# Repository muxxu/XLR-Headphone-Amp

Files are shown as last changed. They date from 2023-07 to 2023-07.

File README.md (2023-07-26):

## Symmetric XLR Headphone Amplifier

In this repo you will find a headphone amplifier mainly developed for in-ear monitoring.

The amplifier is designed to be driven with symmetrical audio signals connected via XLR. It converts the symmetrical signals (Left and Right for stereo or only Right for mono, switchable) to an unsymmetrical signal. This signal is further amplified to drive headphones or in-ears. Beside the complete eagle schematics and board files, the repo contains a 3D printable casing. It is designed so that it can be attached to your belt. The amplifier is powered by 2-AA battery cells. These should last easily 50 hours, so enough time for some band sessions or concerts.

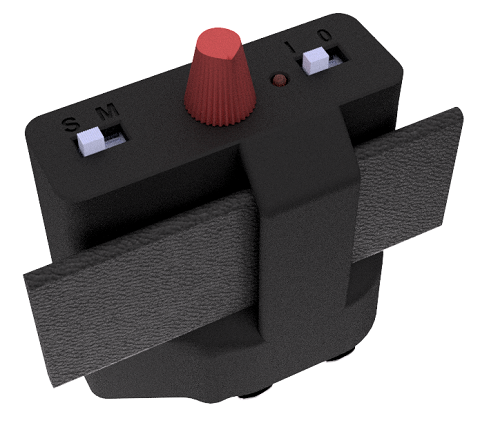
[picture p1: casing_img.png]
Image of Casing

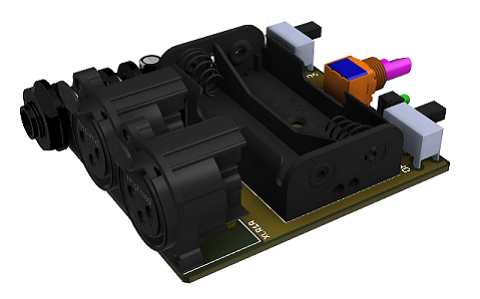
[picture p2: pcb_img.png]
Image of PCB


If you are interested in building one or have any questions feel free to contact me.

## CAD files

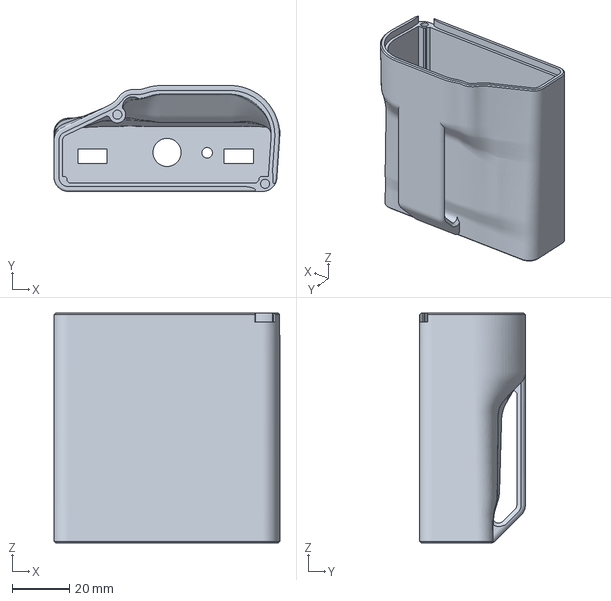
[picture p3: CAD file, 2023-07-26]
casing/mainbody.3mf
78.8 x 36.9 x 80.1 mm

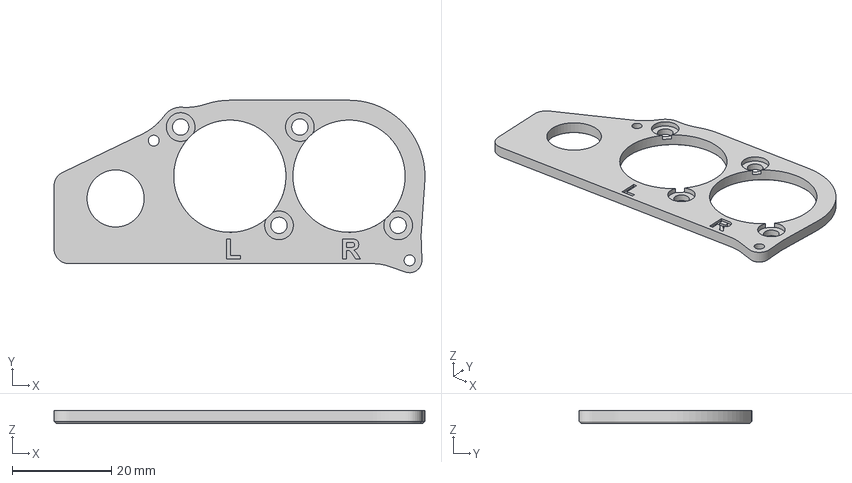
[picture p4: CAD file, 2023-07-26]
casing/cover.3mf
74.7 x 34.8 x 2.60 mm

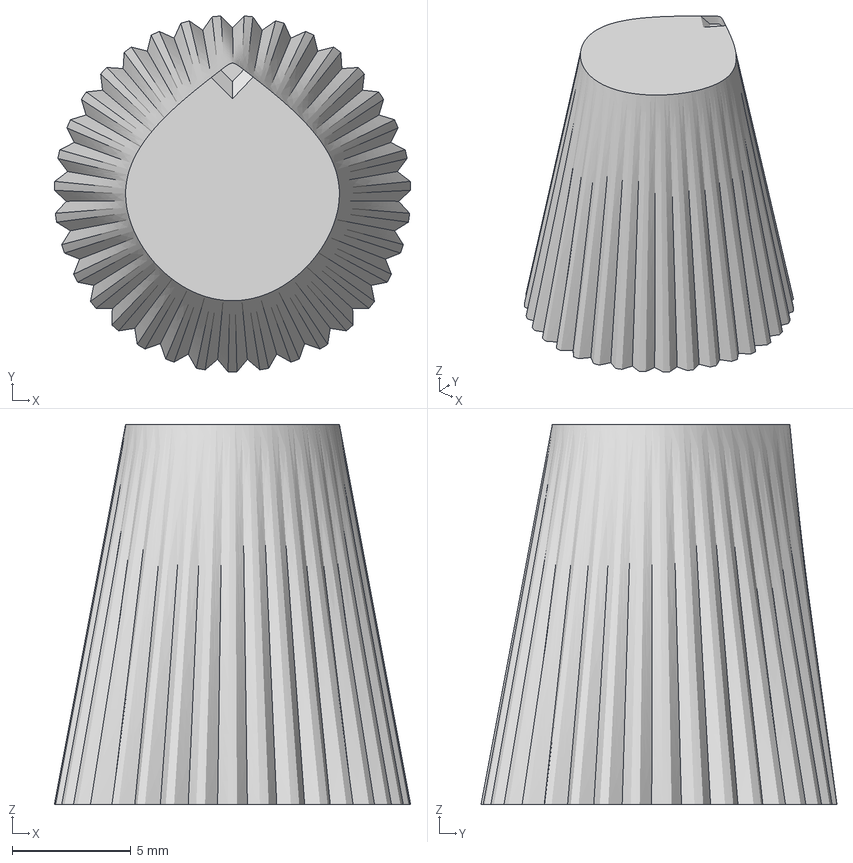
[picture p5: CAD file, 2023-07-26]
casing/knob.3mf
15.0 x 15.0 x 16.0 mm

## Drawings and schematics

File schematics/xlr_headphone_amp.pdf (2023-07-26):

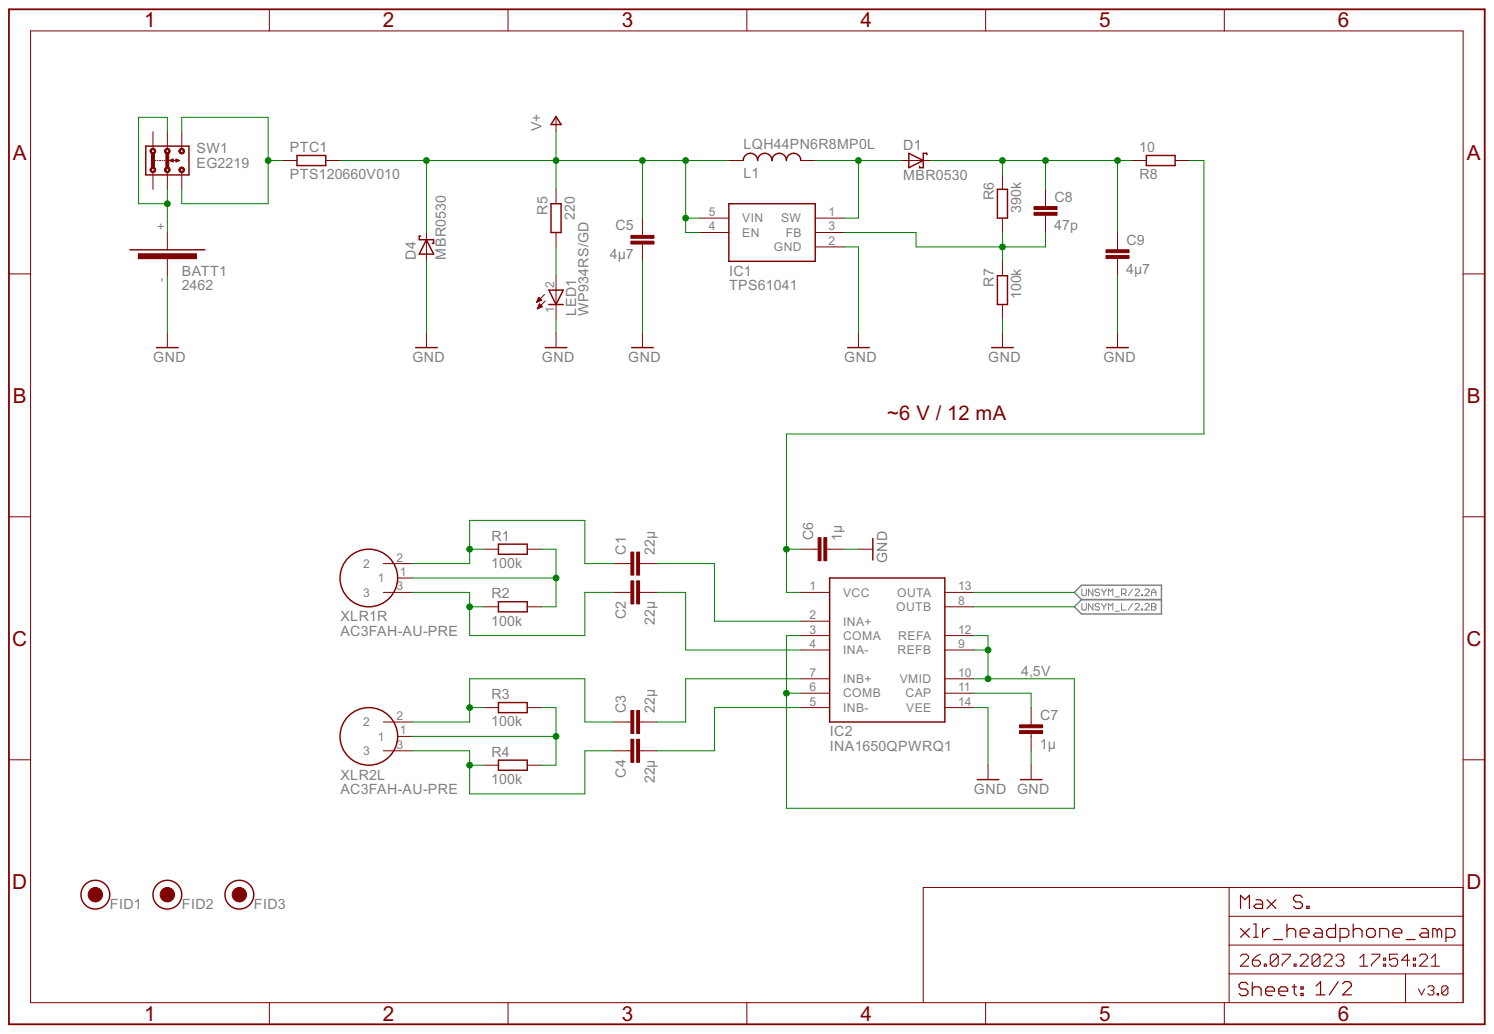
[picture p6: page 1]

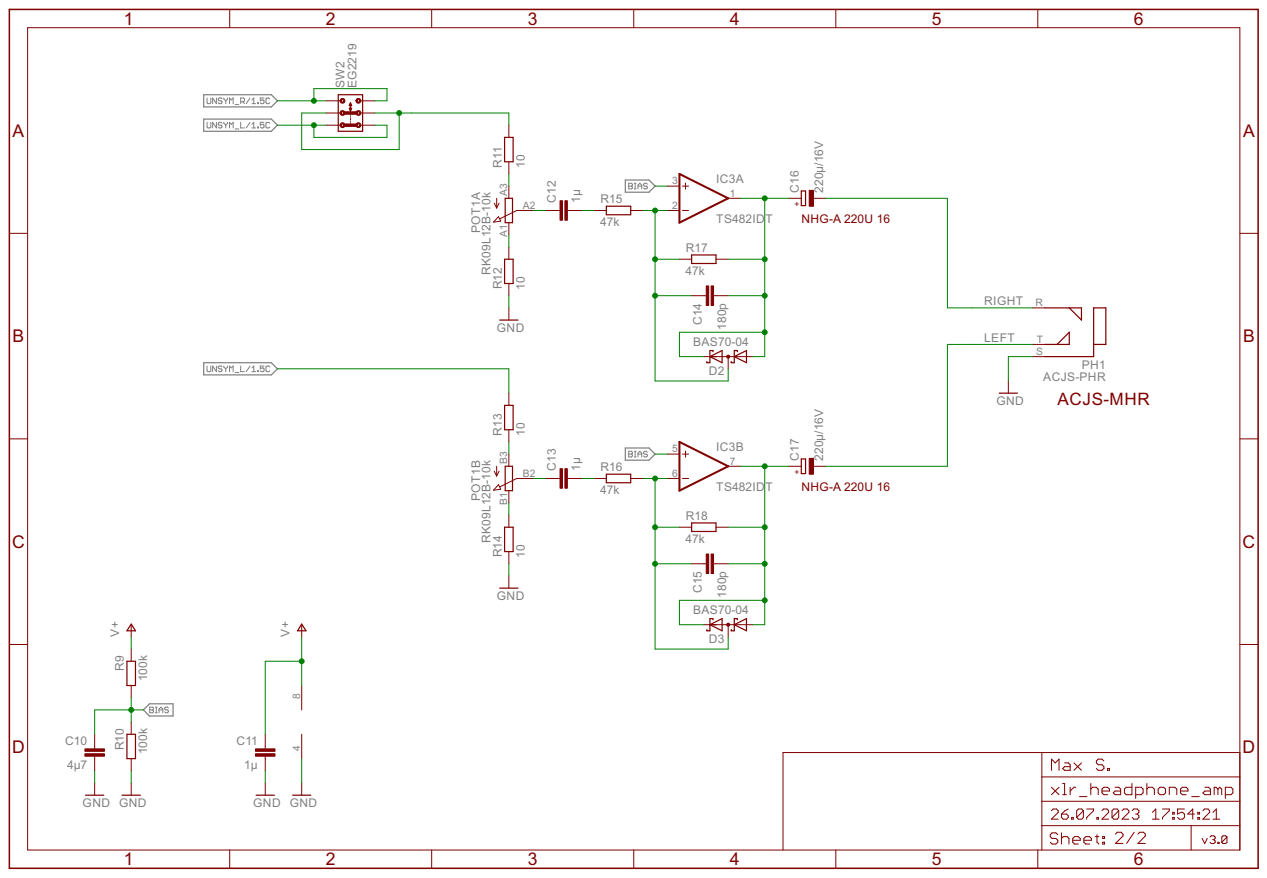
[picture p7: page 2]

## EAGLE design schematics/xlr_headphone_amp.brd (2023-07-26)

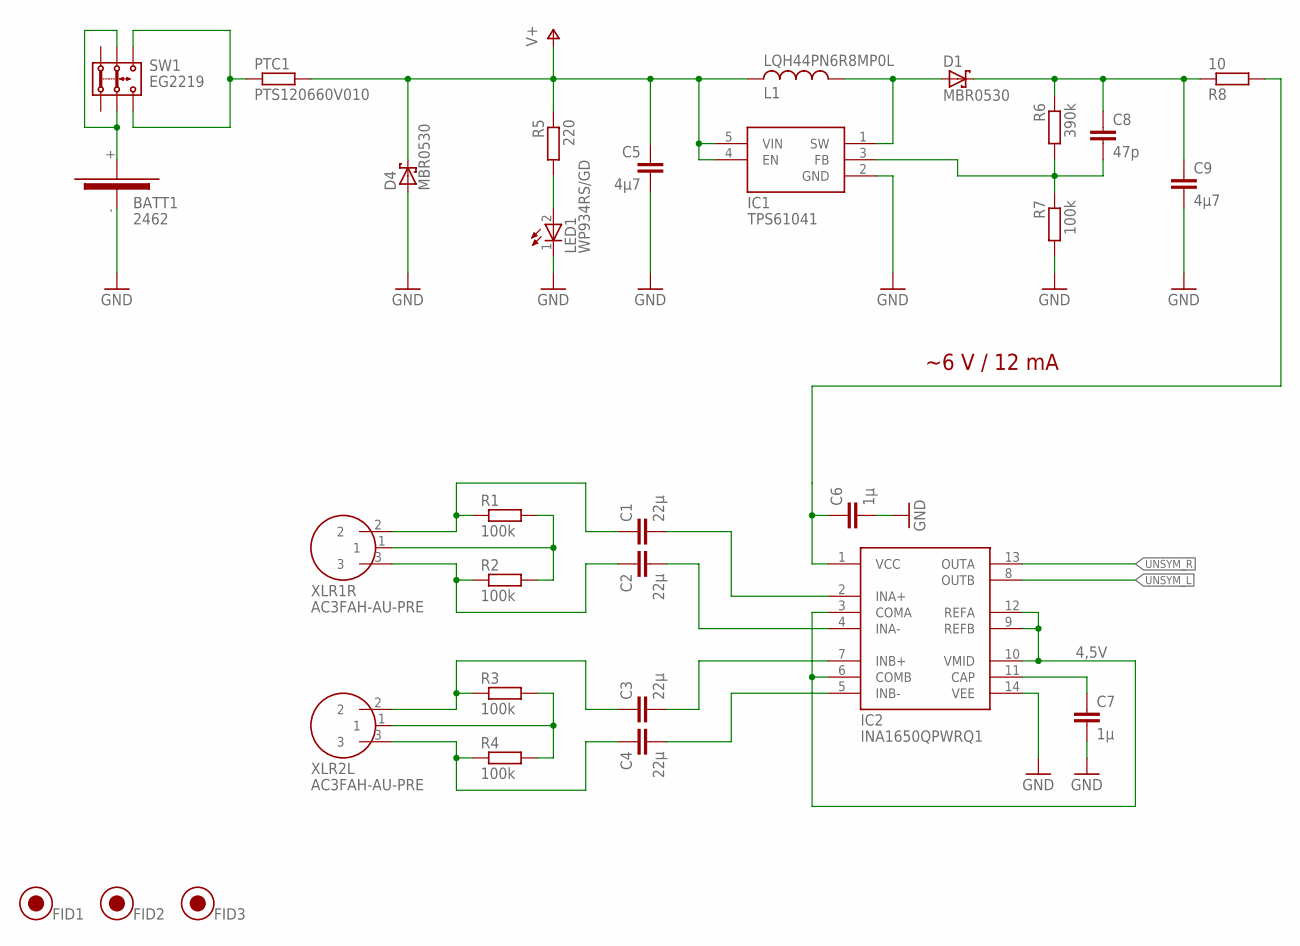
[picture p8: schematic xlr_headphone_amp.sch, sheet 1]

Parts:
BATT1: 2462
C1, C2, C3, C4: 22µ; C1206
C5, C9: 4µ7; C1206
C6, C7: 1µ; C1206
C8: 47p; C1206
D1, D4: MBR0530; SOD123
FID1, FID2, FID3: FIDICUAL
IC1: TPS61041; SOT23-5
IC2: INA1650QPWRQ1; R-PDSO-G14
L1: LQH44PN6R8MP0L; L1515(4040)
LED1: WP934RS/GD; WP934
PTC1: PTS120660V010; R1206
R1, R2, R3, R4, R7: 100k; R1206
R5: 220; R1206
R6: 390k; R1206
R8: 10; R1206
SW1: EG2219
XLR1R, XLR2L: AC3FAH-AU-PRE; AC3FAH

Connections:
4,5V: IC2.3 (COMA), IC2.6 (COMB), IC2.9 (REFB), IC2.10 (VMID), IC2.12 (REFA)
GND: BATT1.- (NEG), C5.2, C6.2, C7.2, C9.2, D4.A, IC1.2 (GND), IC2.14 (VEE), LED1.1 (C), R7.2; also elsewhere on the board
unnamed: R1.2, R2.2, XLR1R.1
unnamed: C1.1, R1.1, XLR1R.2
unnamed: C2.1, R2.1, XLR1R.3
unnamed: C1.2, IC2.2 (INA+)
unnamed: C2.2, IC2.4 (INA-)
unnamed: R3.2, R4.2, XLR2L.1
unnamed: C3.1, R3.1, XLR2L.2
unnamed: C4.1, R4.1, XLR2L.3
unnamed: C3.2, IC2.7 (INB+)
unnamed: C4.2, IC2.5 (INB-)
unnamed: C7.1, IC2.11 (CAP)
unnamed: LED1.2 (A), R5.2
unnamed: D1.A, IC1.1 (SW), L1.1
unnamed: C8.2, IC1.3 (FB), R6.2, R7.1
unnamed: C8.1, C9.1, D1.C, R6.1, R8.1
unnamed: BATT1.+ (POS), SW1.B1, SW1.B2
unnamed: PTC1.1, SW1.C1, SW1.C2
unnamed: C6.1, IC2.1 (VCC), R8.2
UNSYM_L: IC2.8 (OUTB); also elsewhere on the board
UNSYM_R: IC2.13 (OUTA); also elsewhere on the board
V+: C5.1, D4.C, IC1.4 (EN), IC1.5 (VIN), L1.2, PTC1.2, R5.1; also elsewhere on the board

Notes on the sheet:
~6 V / 12 mA

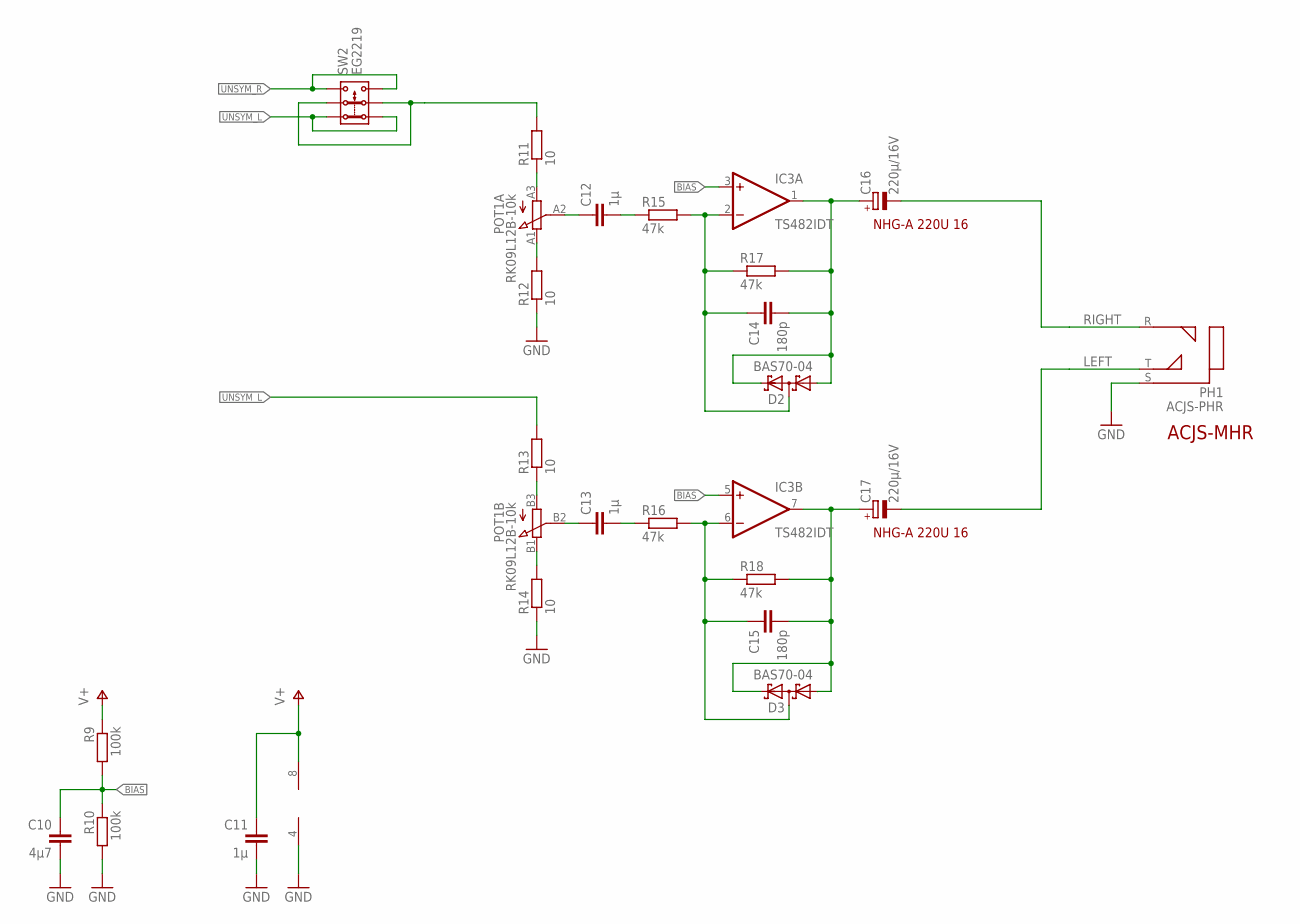
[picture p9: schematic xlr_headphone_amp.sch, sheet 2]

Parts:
C10: 4µ7; C1206
C11, C12, C13: 1µ; C1206
C14, C15: 180p; C1206
C16, C17: 220µ/16V; E2,5-6
D2, D3: BAS70-04; SOT23
IC3: TS482IDT; SO08
PH1: ACJS-PHR; ACJS
POT1: RK09L12B-10k; RK09L12
R9, R10: 100k; R1206
R11, R12, R13, R14: 10; R1206
R15, R16, R17, R18: 47k; R1206
SW2: EG2219

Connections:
BIAS: C10.1, IC3.3 (+IN), IC3.5 (+IN), R9.2, R10.1
GND: C10.2, C11.2, IC3.4 (V-), PH1.S, R10.2, R12.1, R14.1; also elsewhere on the board
LEFT: C17.-, PH1.T
unnamed: POT1.B1 (1), R14.2
unnamed: POT1.B3 (3), R13.1
unnamed: C14.1, D2.3 (C1A2), IC3.2 (-IN), R15.2, R17.1
unnamed: R11.2, SW2.B1, SW2.B2
unnamed: C13.1, POT1.B2 (2)
unnamed: POT1.A1 (1), R12.2
unnamed: C12.2, R15.1
unnamed: C12.1, POT1.A2 (2)
unnamed: C15.1, D3.3 (C1A2), IC3.6 (-IN), R16.2, R18.1
unnamed: C15.2, C17.+, D3.1 (A1), D3.2 (C2), IC3.7 (OUT), R18.2
unnamed: POT1.A3 (3), R11.1
unnamed: C13.2, R16.1
unnamed: C14.2, C16.+, D2.1 (A1), D2.2 (C2), IC3.1 (OUT), R17.2
RIGHT: C16.-, PH1.R
UNSYM_L: R13.2, SW2.A1, SW2.A2; also elsewhere on the board
UNSYM_R: SW2.C1, SW2.C2; also elsewhere on the board
V+: C11.1, IC3.8 (V+), R9.1; also elsewhere on the board

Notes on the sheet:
NHG-A 220U 16
ACJS-MHR

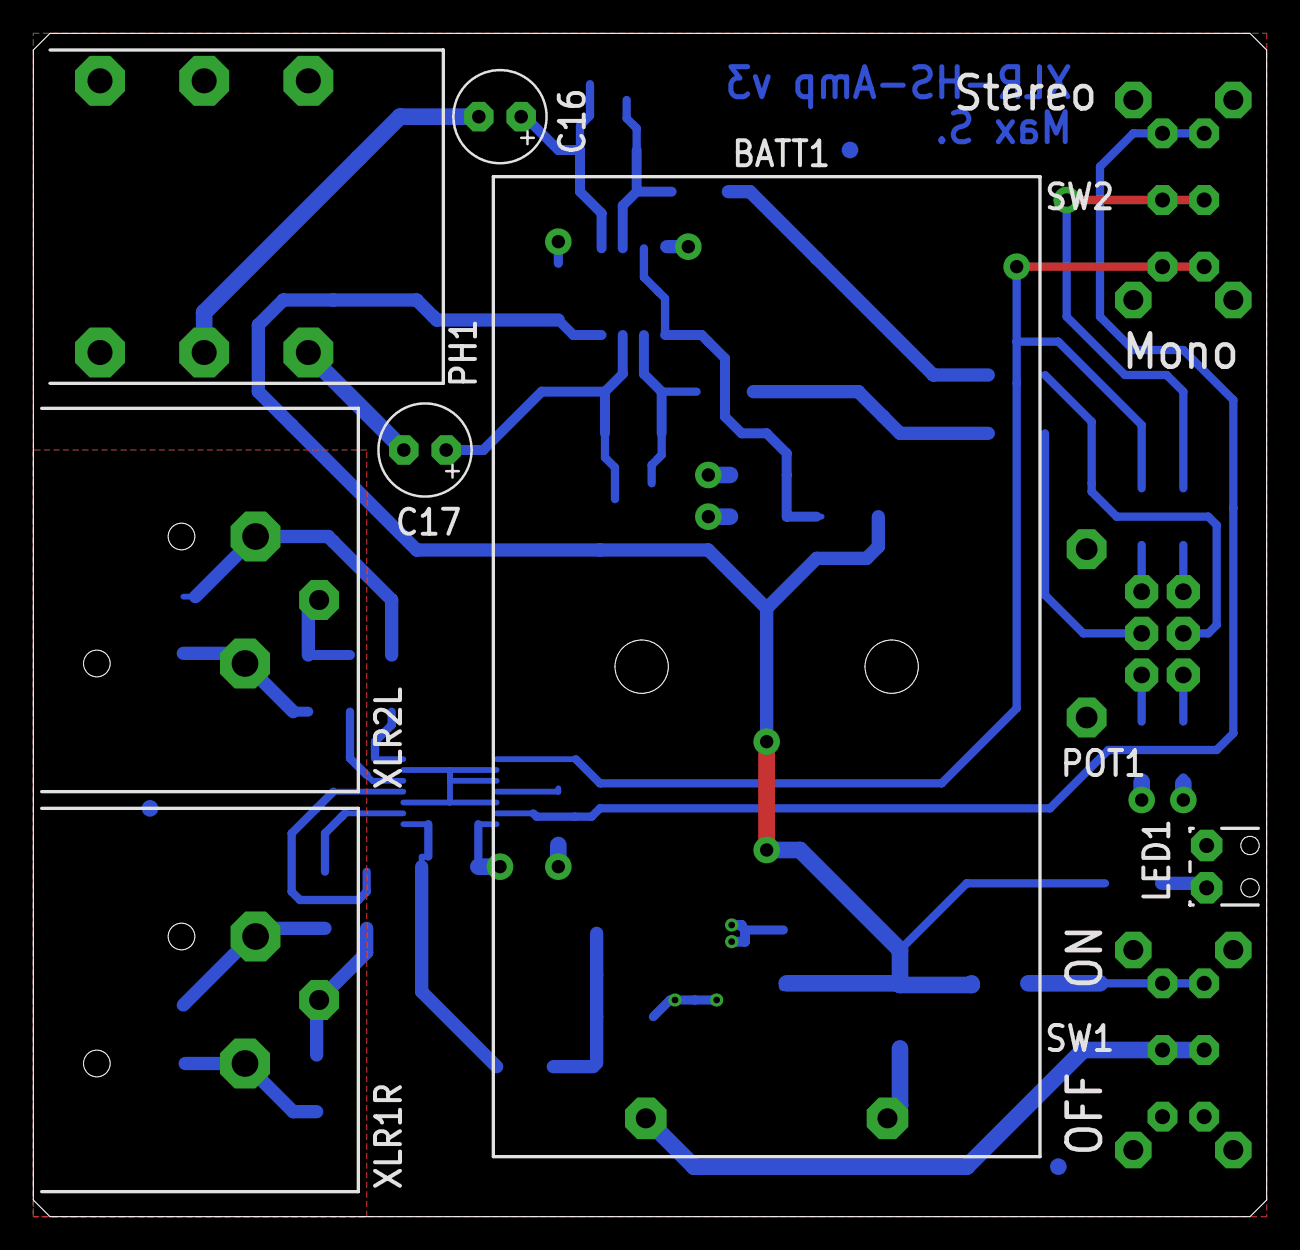
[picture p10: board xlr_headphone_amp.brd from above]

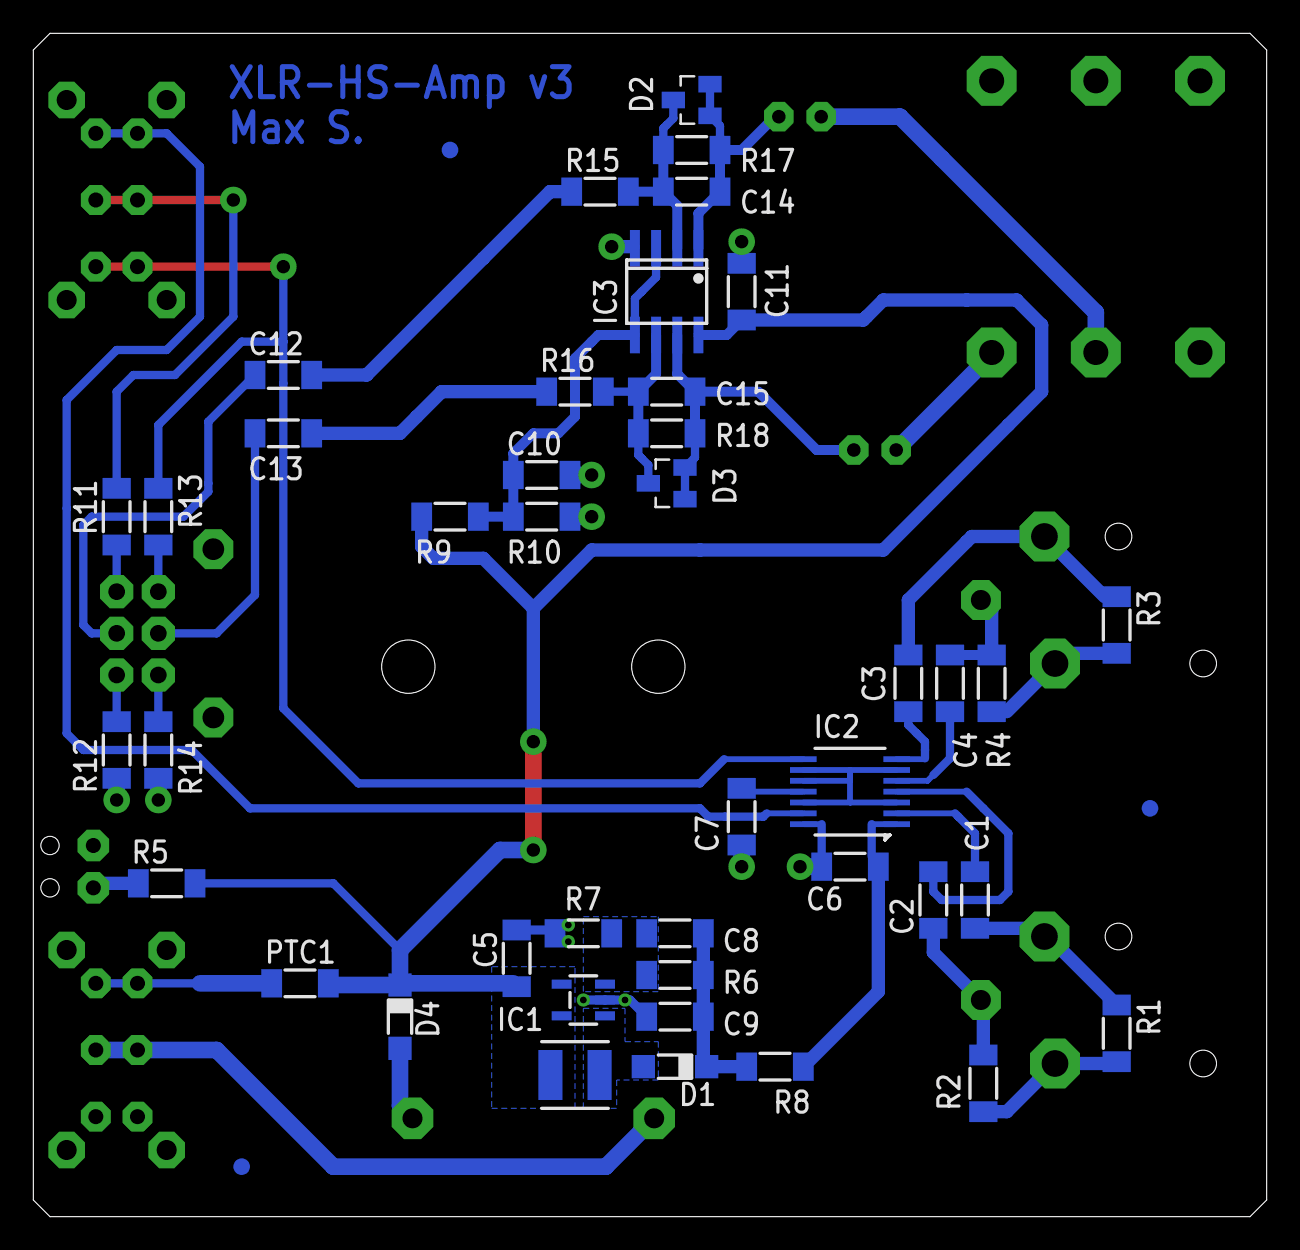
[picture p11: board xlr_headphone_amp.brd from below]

Board: 2 copper layers, 74.0 x 71.0 mm, 55 parts (45 on the bottom side), 39 nets.
